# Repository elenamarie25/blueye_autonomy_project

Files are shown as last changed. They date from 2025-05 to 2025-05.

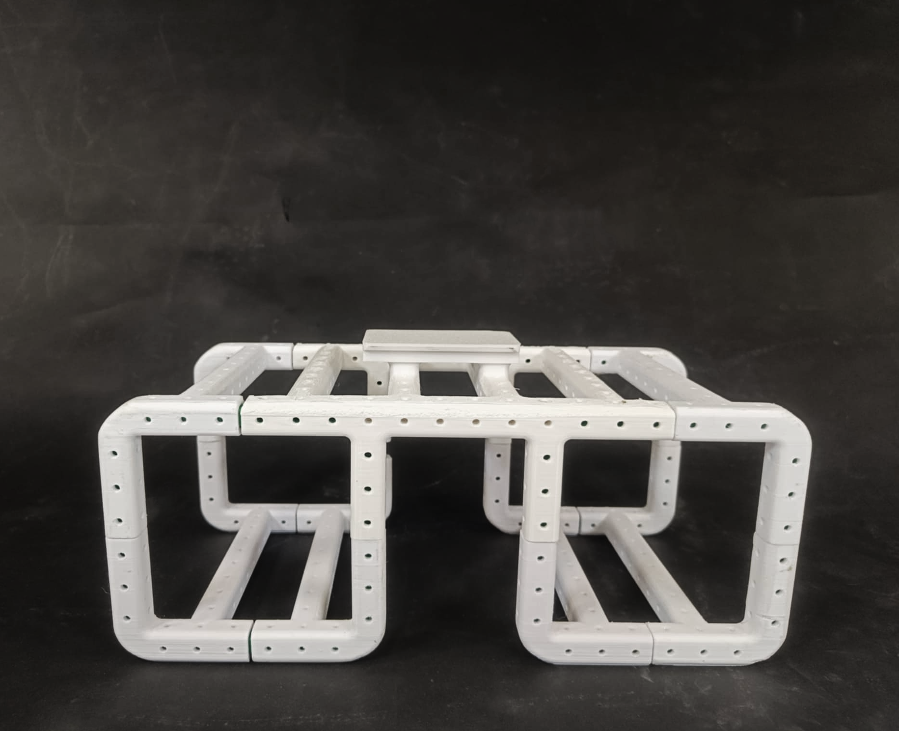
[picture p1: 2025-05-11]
images/Whole frame.png

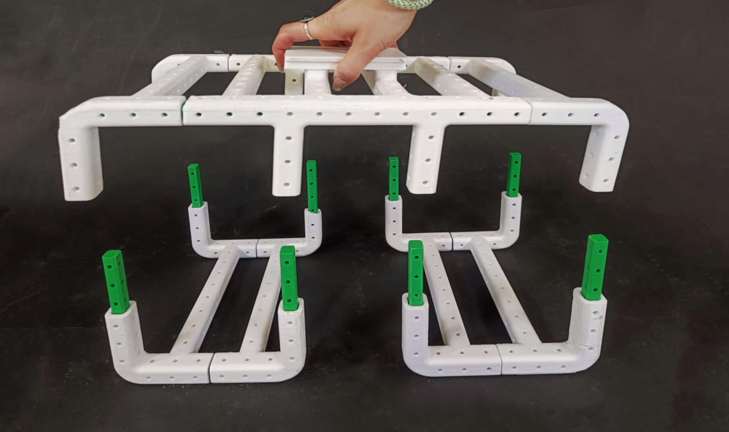
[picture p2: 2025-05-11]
images/Connecting frame.png

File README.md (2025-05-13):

# Modular Sensor Mounting System for Blueye ROV

This open-source library contains 3D-printable mounting solutions for attaching various sensors to the Blueye ROV.

The mounts are designed to fit specific sensors such as:
- USBL modem
- DVL (Doppler Velocity Log)
- Compute Bottle
- Forward-looking sonar
- Inductive charging coil

## 🔧 Customization
The files are provided in .STL (ready to print) and .STEP (editable) formats as well as CAD links so that users can adapt the mounts for their own sensor configurations or ROV modifications.

## 📦 What's included
- Mounting base designs
- Modular connector elements
- Sensor-specific brackets
- Assembly documentation and How-to's

## 🗂 Folder Overview

- `/original_files/` – Official mounting parts made by our team. Please don’t modify these directly.
- `/community_mods/` – Modified or remixed versions contributed by the community.
- `/images/` – Previews and renders of the models.
- `/how-to/` – Guides for printing, designing and assembling.

## 📄 License
These files are shared under the **Creative Commons Attribution-NonCommercial-ShareAlike 4.0 International (CC BY-NC-SA 4.0)** license.  
This means you're free to remix, adapt, and build upon this work non-commercially, as long as you credit the original creators and license your new creations under the same terms.

## 🛠 Contributing or Remixing

Please **do not modify the files in `/original_files/`**.  
If you'd like to make your own version, upload your modified file to the `/community_mods/` folder and include your name or version in the filename.

This keeps the original library intact while allowing remixing and experimentation.

## ✉️ Contact
If you use or modify this project, feel free to share your results or improvements.  
Developed by design students at NTNU as part of the Spring 2024 course "Design 6 – Futures" in collaboration with Blueye Robotics.

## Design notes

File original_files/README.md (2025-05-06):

## 🗂 original_files
Official mounting parts made by our team. Please don’t modify these directly.

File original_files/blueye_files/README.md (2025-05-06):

## 🗂 blueye_files
The origional CAD models for the Blueye sensors and Blueye robot.

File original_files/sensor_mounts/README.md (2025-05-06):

## 🗂 sensor_mounts
The sensor mounts for the sensors used in the Blueye AUV project

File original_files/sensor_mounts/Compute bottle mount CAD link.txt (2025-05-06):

Compute bottle mount link:
https://a360.co/4m7CdN2

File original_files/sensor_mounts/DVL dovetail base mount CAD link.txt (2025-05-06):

DVL dovetail base mount link
https://a360.co/42Lx19Z

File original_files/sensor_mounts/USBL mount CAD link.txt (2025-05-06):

USBL mount link:
https://a360.co/3Sn9JRv

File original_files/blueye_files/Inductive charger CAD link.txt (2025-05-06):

Inductive charger link:
https://a360.co/3SkSkZM

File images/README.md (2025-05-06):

## 🗂 images
Previews and renders of the models.

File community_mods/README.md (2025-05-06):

## 🗂 community_mods
Modified or remixed versions contributed by the community.

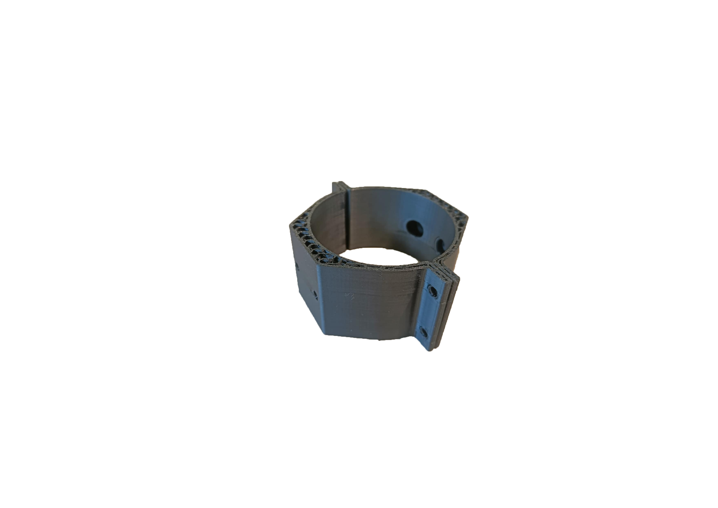
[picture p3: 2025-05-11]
images/USBL mount.png

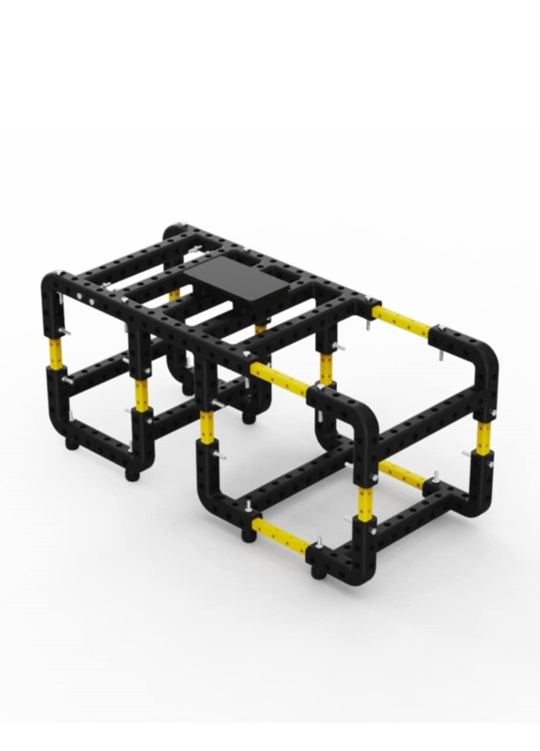
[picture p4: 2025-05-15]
images/Frame render.jpeg

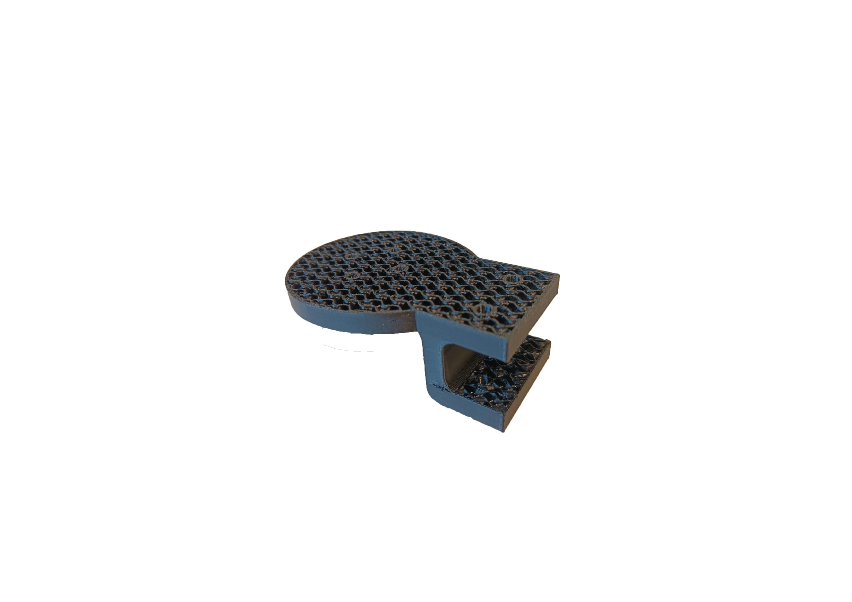
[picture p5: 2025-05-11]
images/DVL mount.png

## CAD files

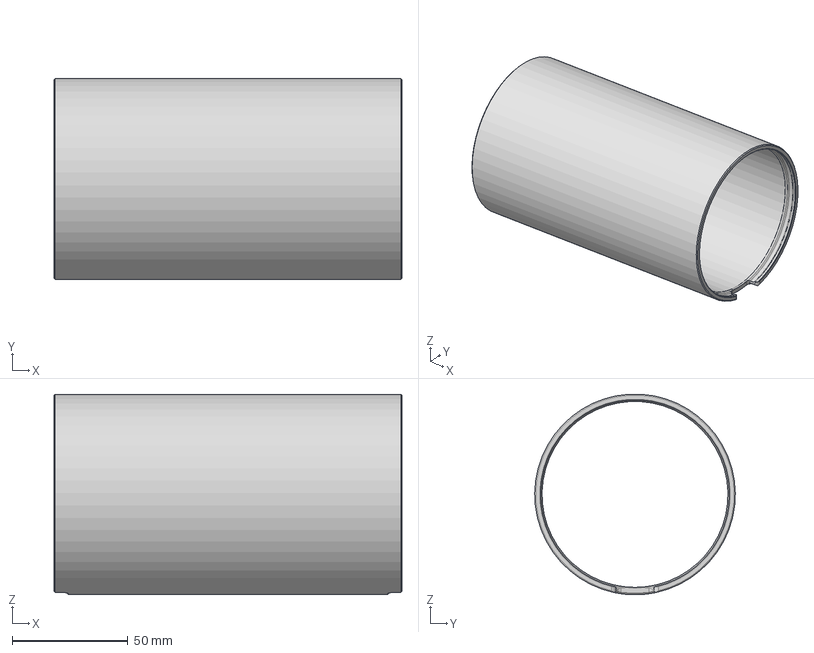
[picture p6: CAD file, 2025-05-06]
original_files/blueye_files/WTE3-M-LOCKING-TUBE-150-R2 v1.step
150.0 x 86.5 x 86.4 mm

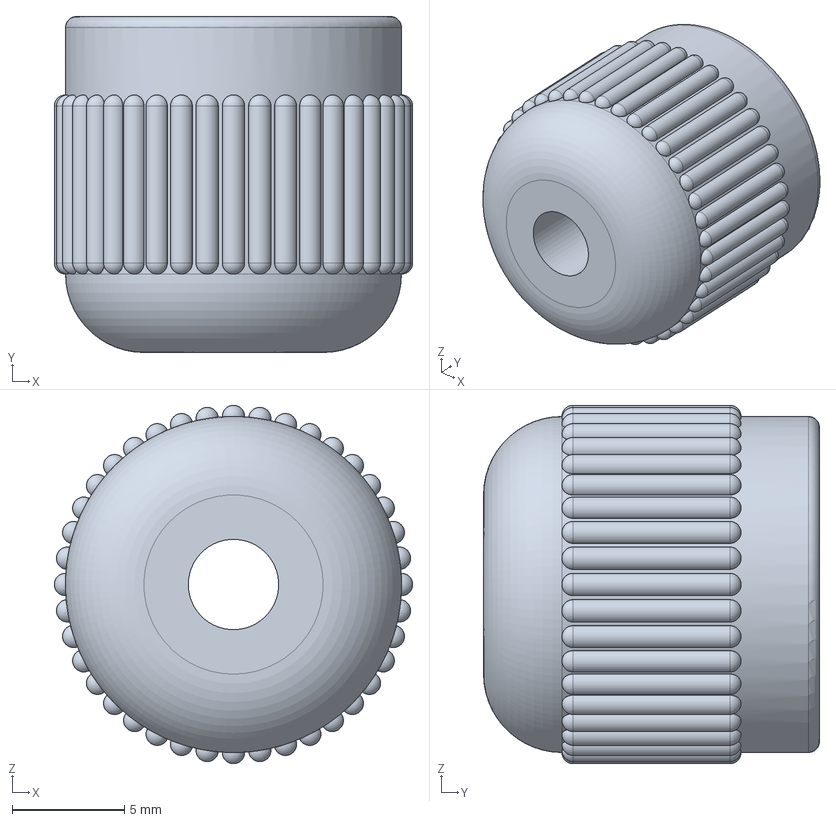
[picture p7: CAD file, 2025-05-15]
original_files/frame/Base supports.step
16.0 x 15.0 x 16.0 mm

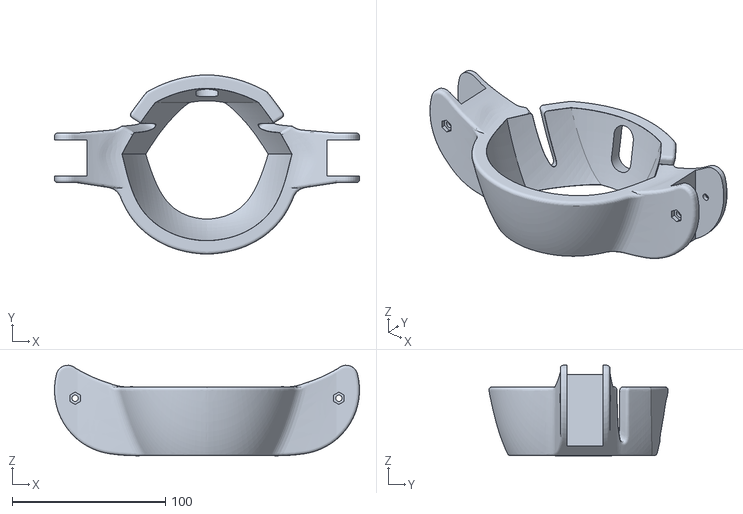
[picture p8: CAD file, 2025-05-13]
original_files/sensor_mounts/Top mount rear.stl
199.1 x 117.0 x 59.1

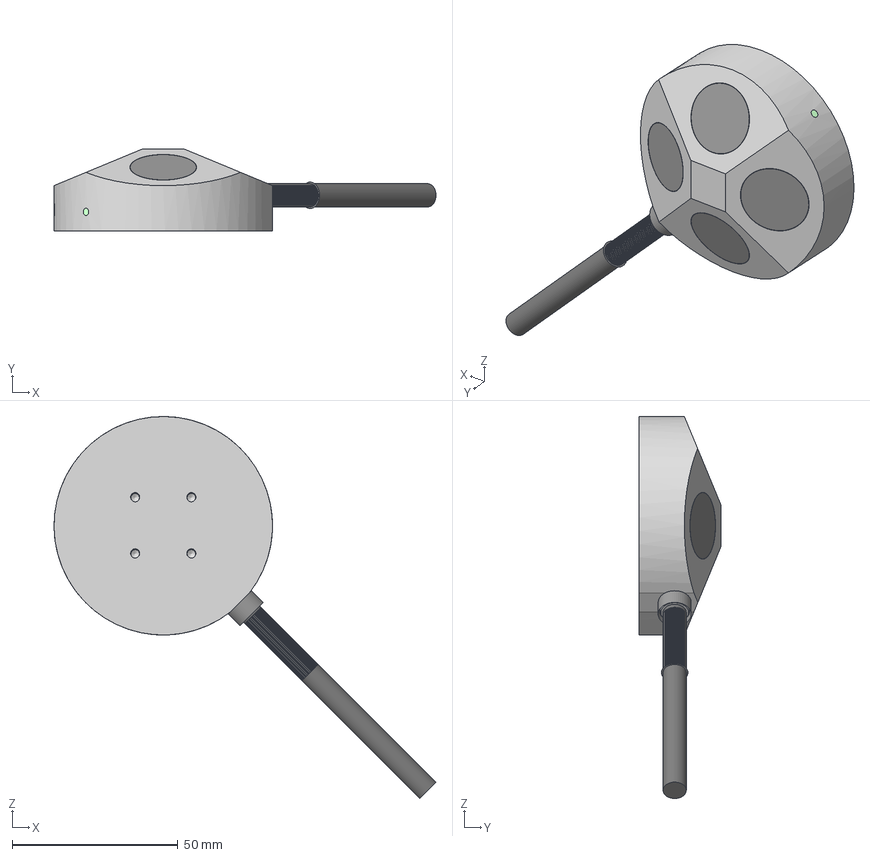
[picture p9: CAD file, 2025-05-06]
original_files/blueye_files/WL-11007-1_DVL.step
115.4 x 24.8 x 115.4 mm

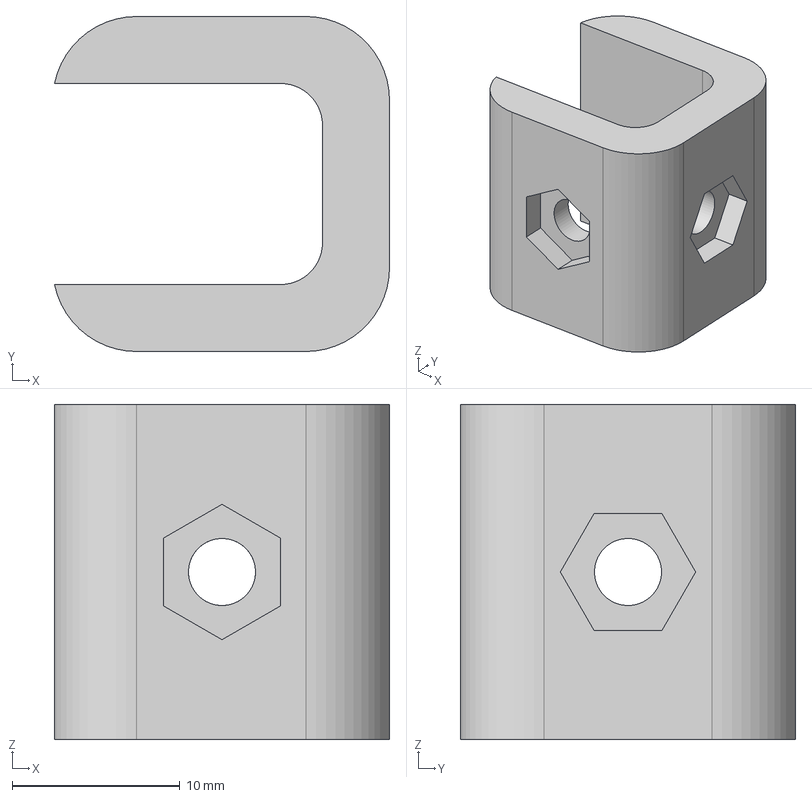
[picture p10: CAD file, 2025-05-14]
original_files/frame/Add on's.step
20.0 x 20.0 x 20.0 mm

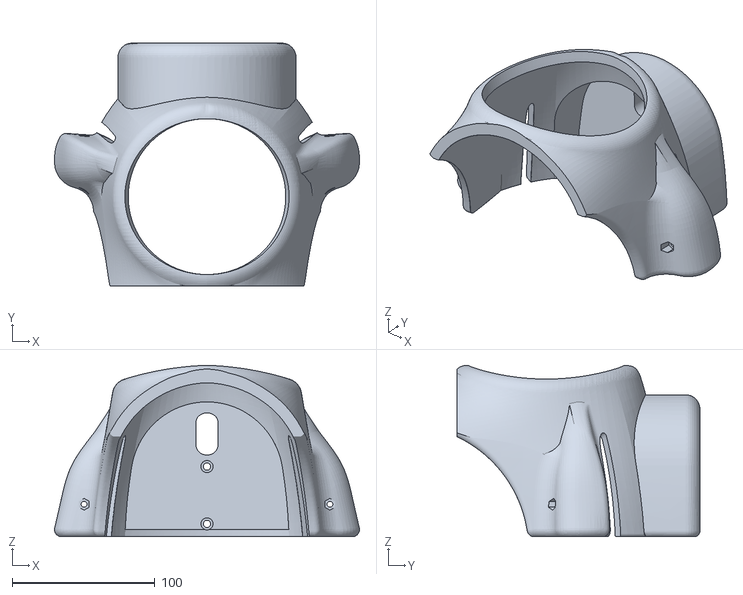
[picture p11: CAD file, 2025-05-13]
original_files/sensor_mounts/Top mount front.stl
213.5 x 170.0 x 120.0

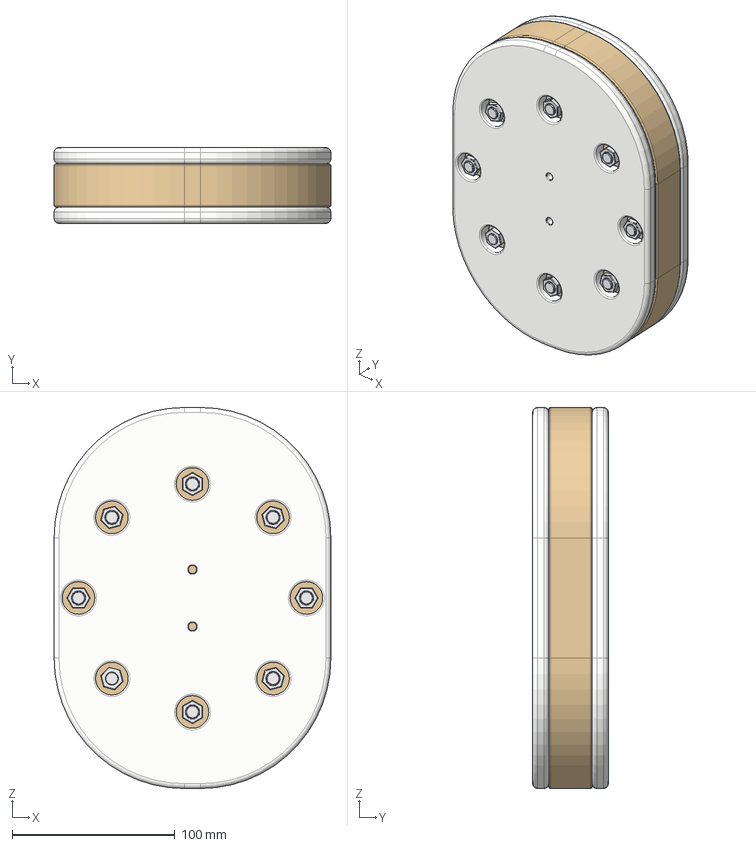
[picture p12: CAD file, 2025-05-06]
original_files/blueye_files/Inductive charger.step
170.0 x 46.5 x 234.0 mm

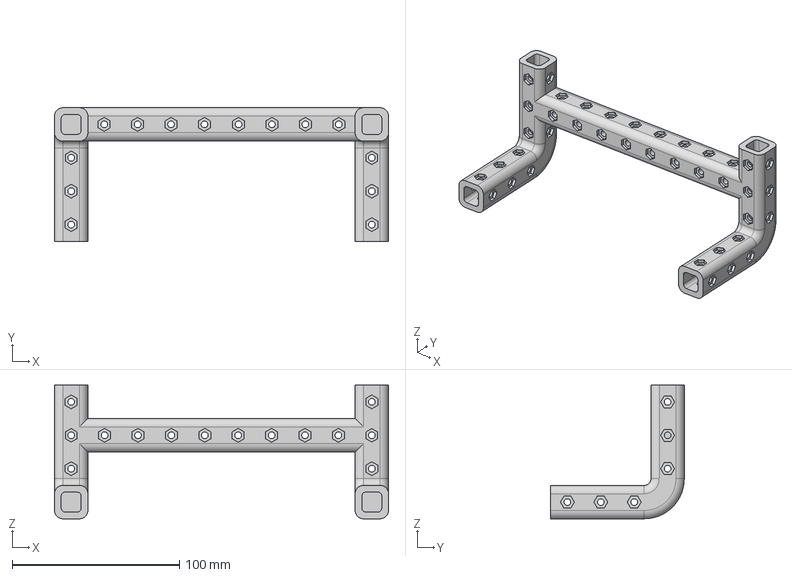
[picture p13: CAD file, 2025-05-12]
original_files/frame/Corner piece.step
200.0 x 80.0 x 80.0 mm

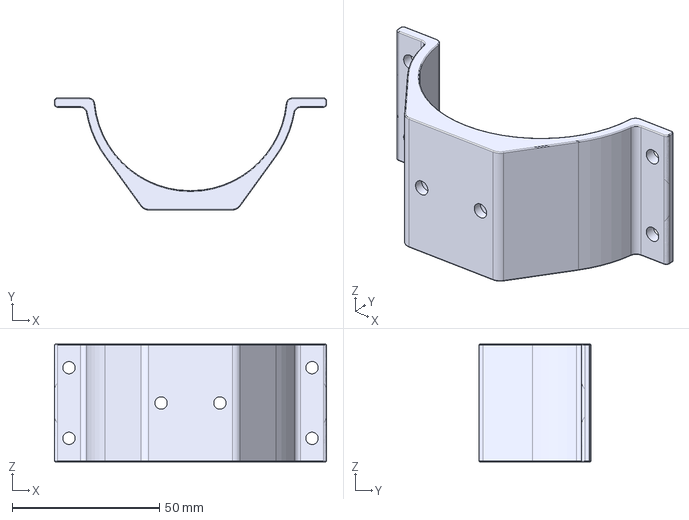
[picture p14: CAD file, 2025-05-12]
original_files/sensor_mounts/USBL mount.step
92.4 x 38.1 x 40.0 mm

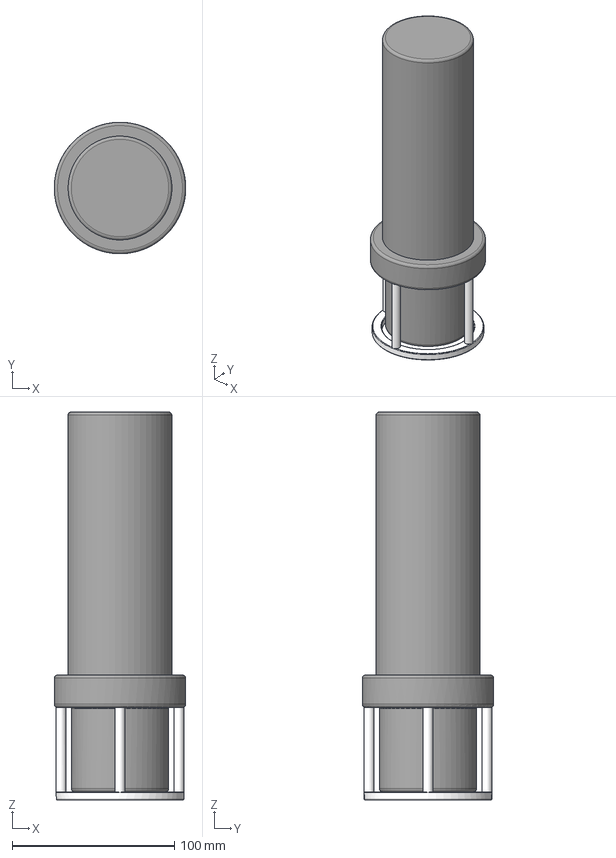
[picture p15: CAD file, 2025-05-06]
original_files/blueye_files/USBL.step
81.0 x 81.0 x 239.0 mm

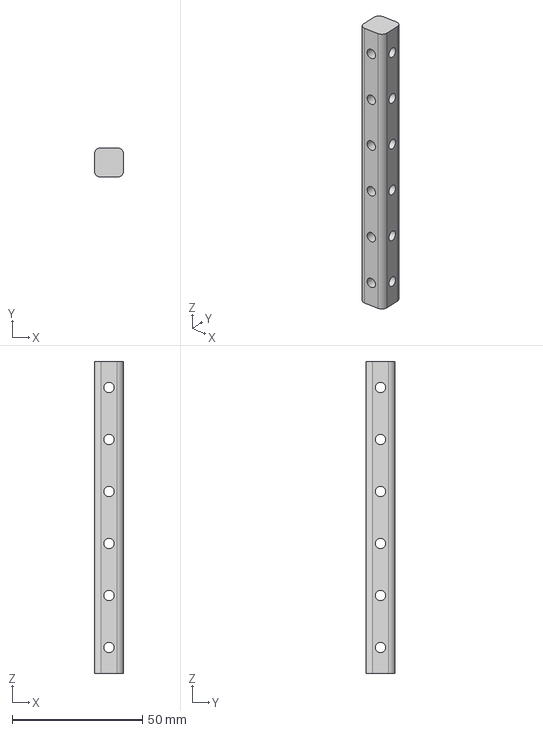
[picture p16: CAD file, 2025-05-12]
original_files/frame/Connecting piece.step
11.3 x 11.3 x 120.0 mm

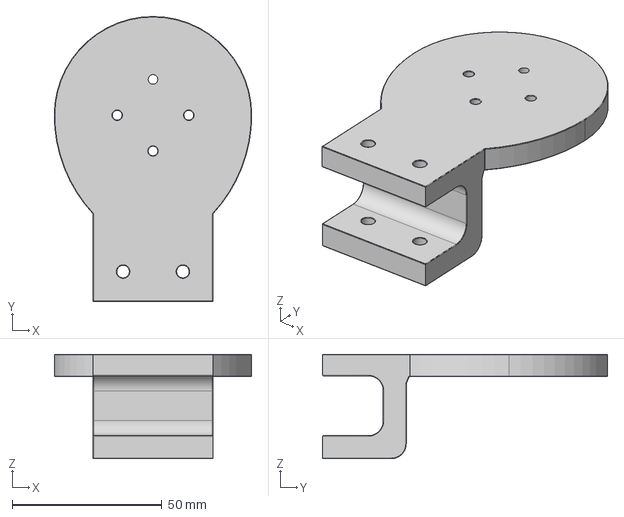
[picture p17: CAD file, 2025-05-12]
original_files/sensor_mounts/Dvl mount.step
66.0 x 95.3 x 34.9 mm

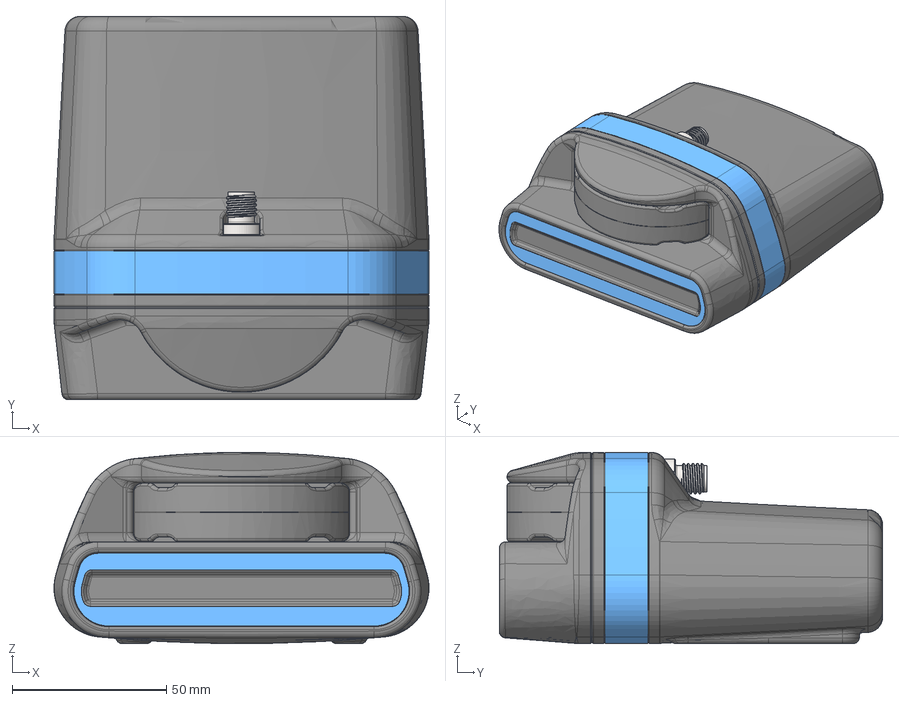
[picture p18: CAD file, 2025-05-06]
original_files/blueye_files/Oculus M-Series Sonar.step
121.6 x 124.3 x 62.0 mm

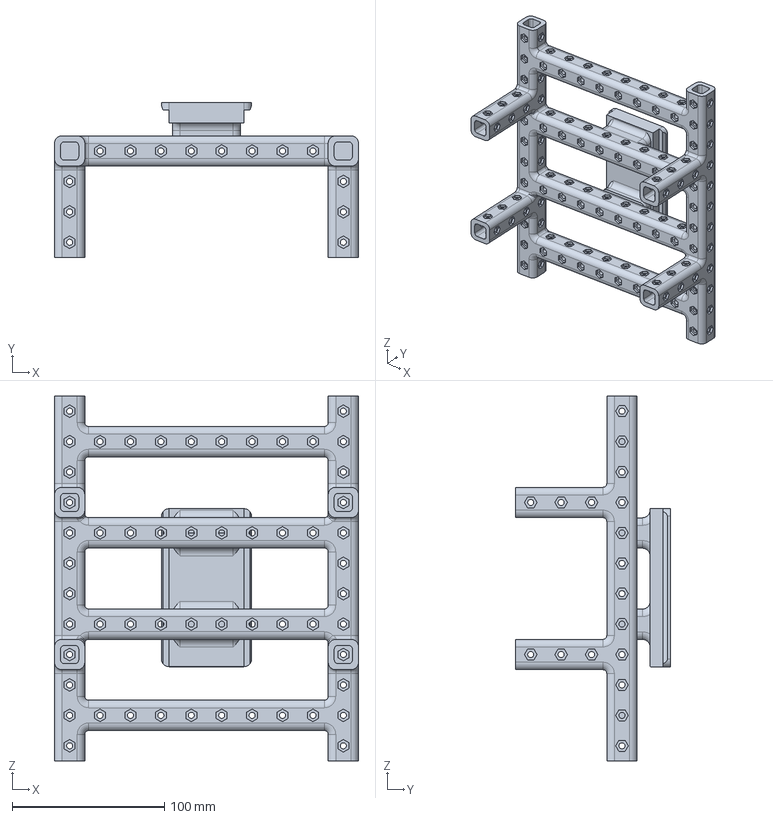
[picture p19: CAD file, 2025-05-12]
original_files/frame/Middle piece.step
200.0 x 101.9 x 240.0 mm

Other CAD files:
original_files/sensor_mounts/sonar mount.step
original_files/blueye_files/Oculus M-Series Sonar v1.stl
original_files/sensor_mounts/Compute bottle mount.step
original_files/sensor_mounts/DVL P001 dovetail base mount.step
original_files/blueye_files/Inductive charger.stl
original_files/blueye_files/USBL.stl
original_files/blueye_files/WL-11007-1_DVL.stl
original_files/blueye_files/WTE3-M-LOCKING-TUBE-150-R2 v1.stl
original_files/frame/Add on's.stl
original_files/frame/Base supports.stl
original_files/frame/Connecting piece.stl
original_files/frame/Corner piece.stl
original_files/frame/Middle piece.stl
original_files/sensor_mounts/Compute bottle mount.stl
original_files/sensor_mounts/DVL P001 dovetail base mount.stl
original_files/sensor_mounts/Dvl mount.stl
original_files/sensor_mounts/USBL mount.stl
original_files/sensor_mounts/sonar mount.stl

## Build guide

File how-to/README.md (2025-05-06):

## 🗂 how-to
Guides for setting up and printing the frame as well as designing and printing the sensor fasteners

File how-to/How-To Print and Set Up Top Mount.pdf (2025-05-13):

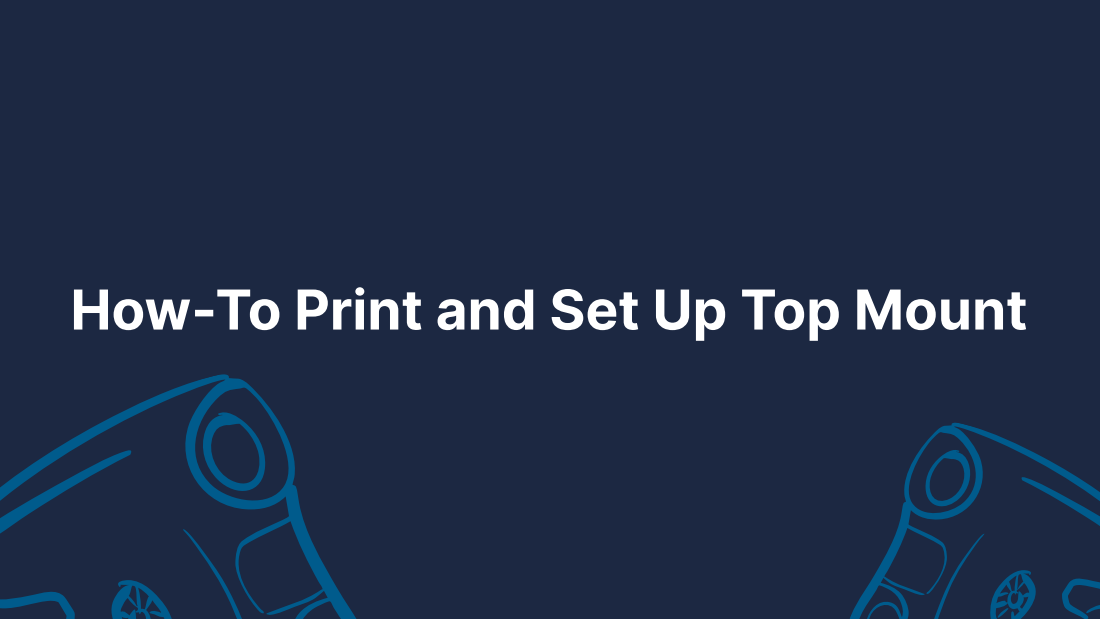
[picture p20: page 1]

How-To Print and Set Up Top Mount

To make the parts airtight increase
to | . It is also
recommended to set
to for increased
durability.

infill density 100%
wall loops/

thickness 5

Airtight and
100% infill

# How-To Print Top Mount

## Printer settings to be mindful of

x Import file into your preferred slicer program.

{x Settings to be mindful ofu
s Filament. Recommended to use
. These work well in saltwaterx
n 100% infill vs. open model and gyroid infill

To prevent implosion in deeper waters, the parts
should either be | or | to let water
run through. Which setting you should use when depends on the desired durability, and which one we recommend for which part is specified in the guides on the next slides.

PETG or PETG-CF

100% infill open

Note:
The examples are from the bamboo slicer but equivalent settings will exist on every slicer program. You only need to change the specified settings, the

rest is fine as-is.

To make an open solution, set
and/or | to | and
change | pattern to

## top bottom shell layer 0 sparse infill “Gyroid”

## Open model and

gyroid infill

# How-To Print Top Mount

## Top Mount - Front piece

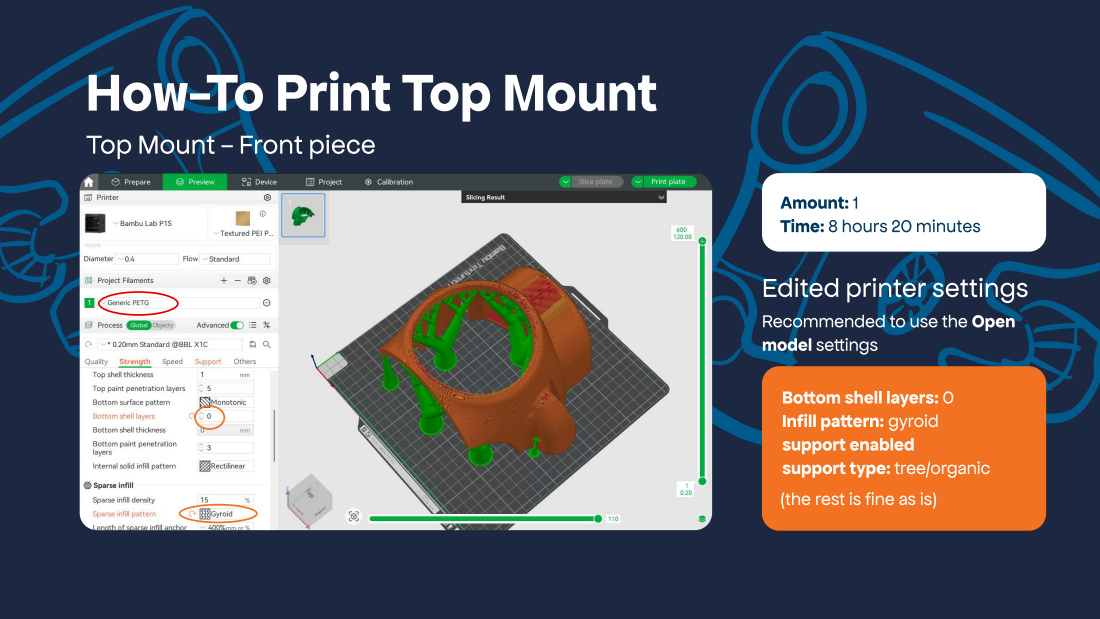
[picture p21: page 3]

Amount: 1
Time: 8 hours 20 minutes

Edited printer settings

Recommended to use the Open
model settings

Bottom shell layers: 0
Infill pattern: gyroid
support enabled
support type: tree/organic

(the rest is fine as is)

# How-To Print Top Mount

# Top Mount - Rear piece

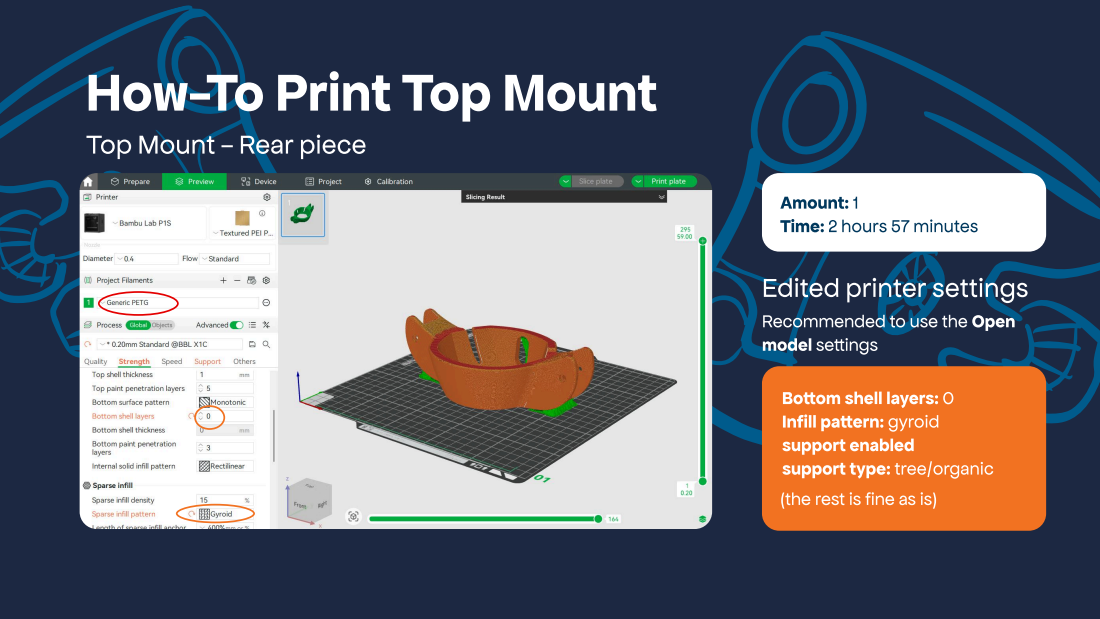
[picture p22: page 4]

Amount: 1
Time: 2 hours 57 minutes

Edited printer settings

Recommended to use the Open
model settings

Bottom shell layers: 0
Infill pattern: gyroid
support enabled
support type: tree/organic
(the rest is fine as is)

# How-To Set Up Top Mount

# Prepare

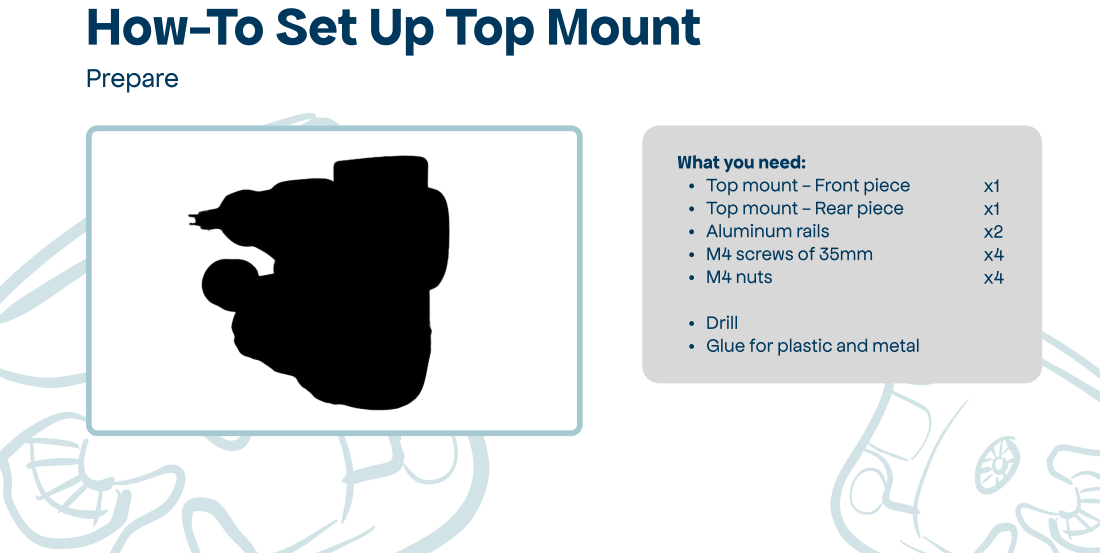
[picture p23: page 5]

What you need:)
' Top mount - Front piece )
' Top mount - Rear piece)
' Aluminum rails)
' M4 screws of 35mm )
' M4 nuts)

' Dril
' Glue for plastic and metal

# How-To Set Up Top Mount

# Prepare aluminium rails

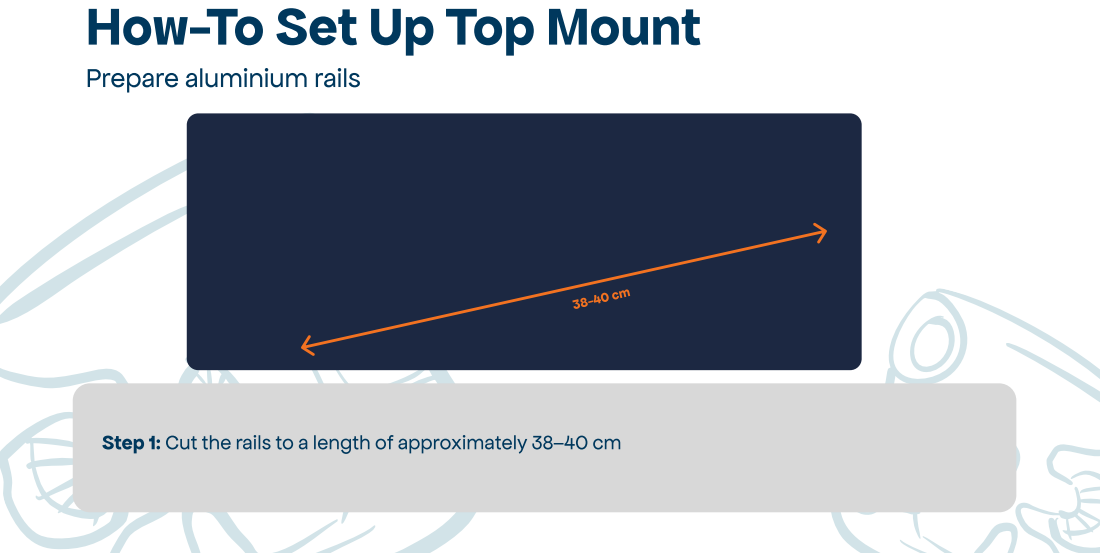
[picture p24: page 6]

Step 1: Cut the rails to a length of approximately 38–40 cm

# How-To Set Up Top Mount

# Prepare aluminium rails

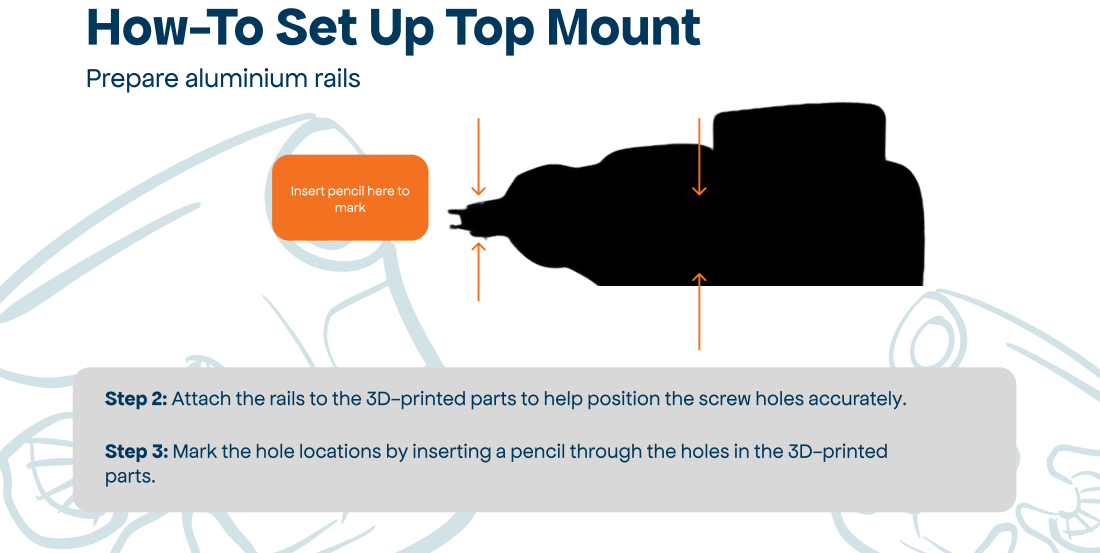
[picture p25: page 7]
mark

Insert pencil here to

Step 2: Attach the rails to the 3D-printed parts to help position the screw holes accurately.

Step 3: Mark the hole locations by inserting a pencil through the holes in the 3D-printed
parts.

# How-To Set Up Top Mount

# Prepare aluminium rails

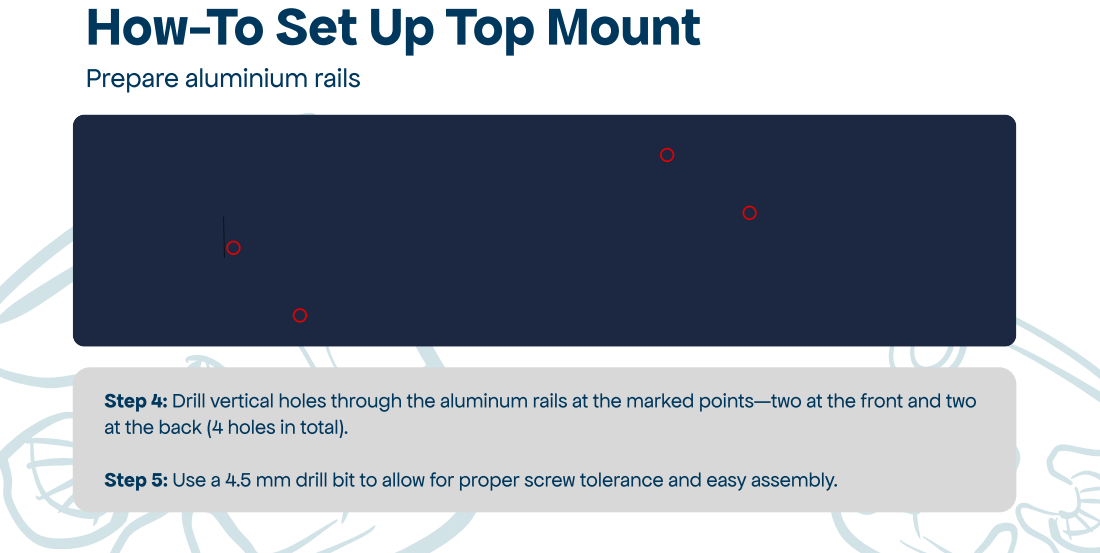
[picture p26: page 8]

Step 4: Drill vertical holes through the aluminum rails at the marked points—two at the front and two
at the back (4 holes in total).

Step 5: Use a 4.5 mm drill bit to allow for proper screw tolerance and easy assembly.

# How-To Set Up Top Mount

Prepare front and rear pieces.

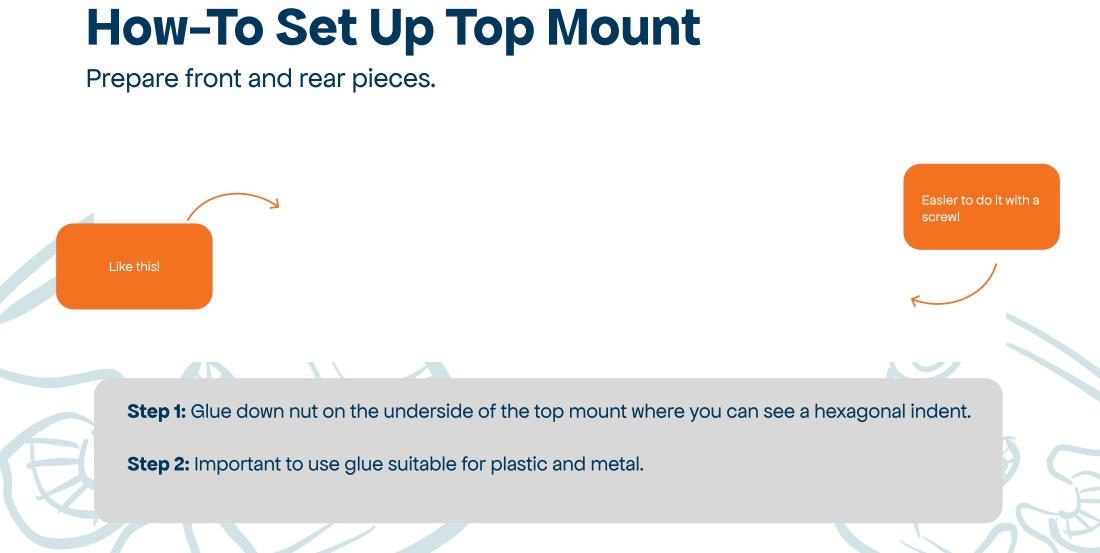
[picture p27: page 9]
Like this!

Easier to do it with a
screw!

Step 1: Glue down nut on the underside of the top mount where you can see a hexagonal indent.

Step 2: Important to use glue suitable for plastic and metal.

# How-To Set Up Top Mount

## Assembly (with inductive charger)

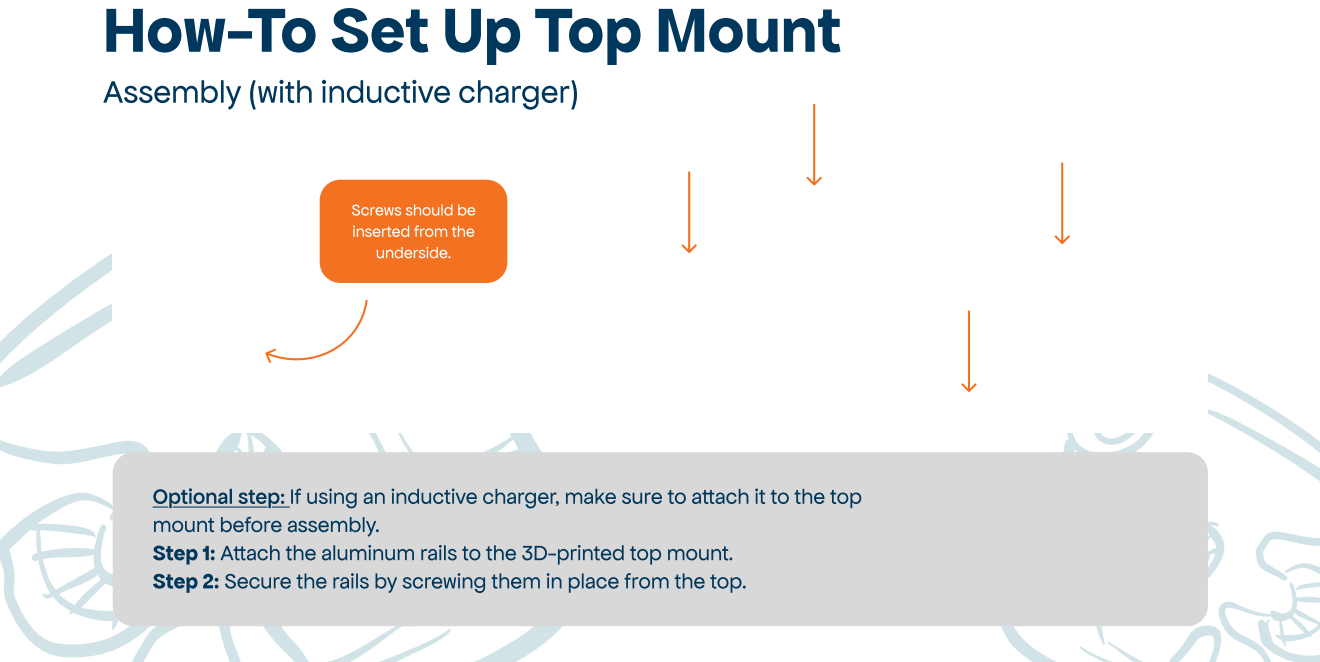
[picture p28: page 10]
underside.

Screws should be

inserted from the

Optional step: If using an inductive charger, make sure to attach it to the top

mount before assembly.
Step 1: Attach the aluminum rails to the 3D-printed top mount.

Step 2: Secure the rails by screwing them in place from the top.

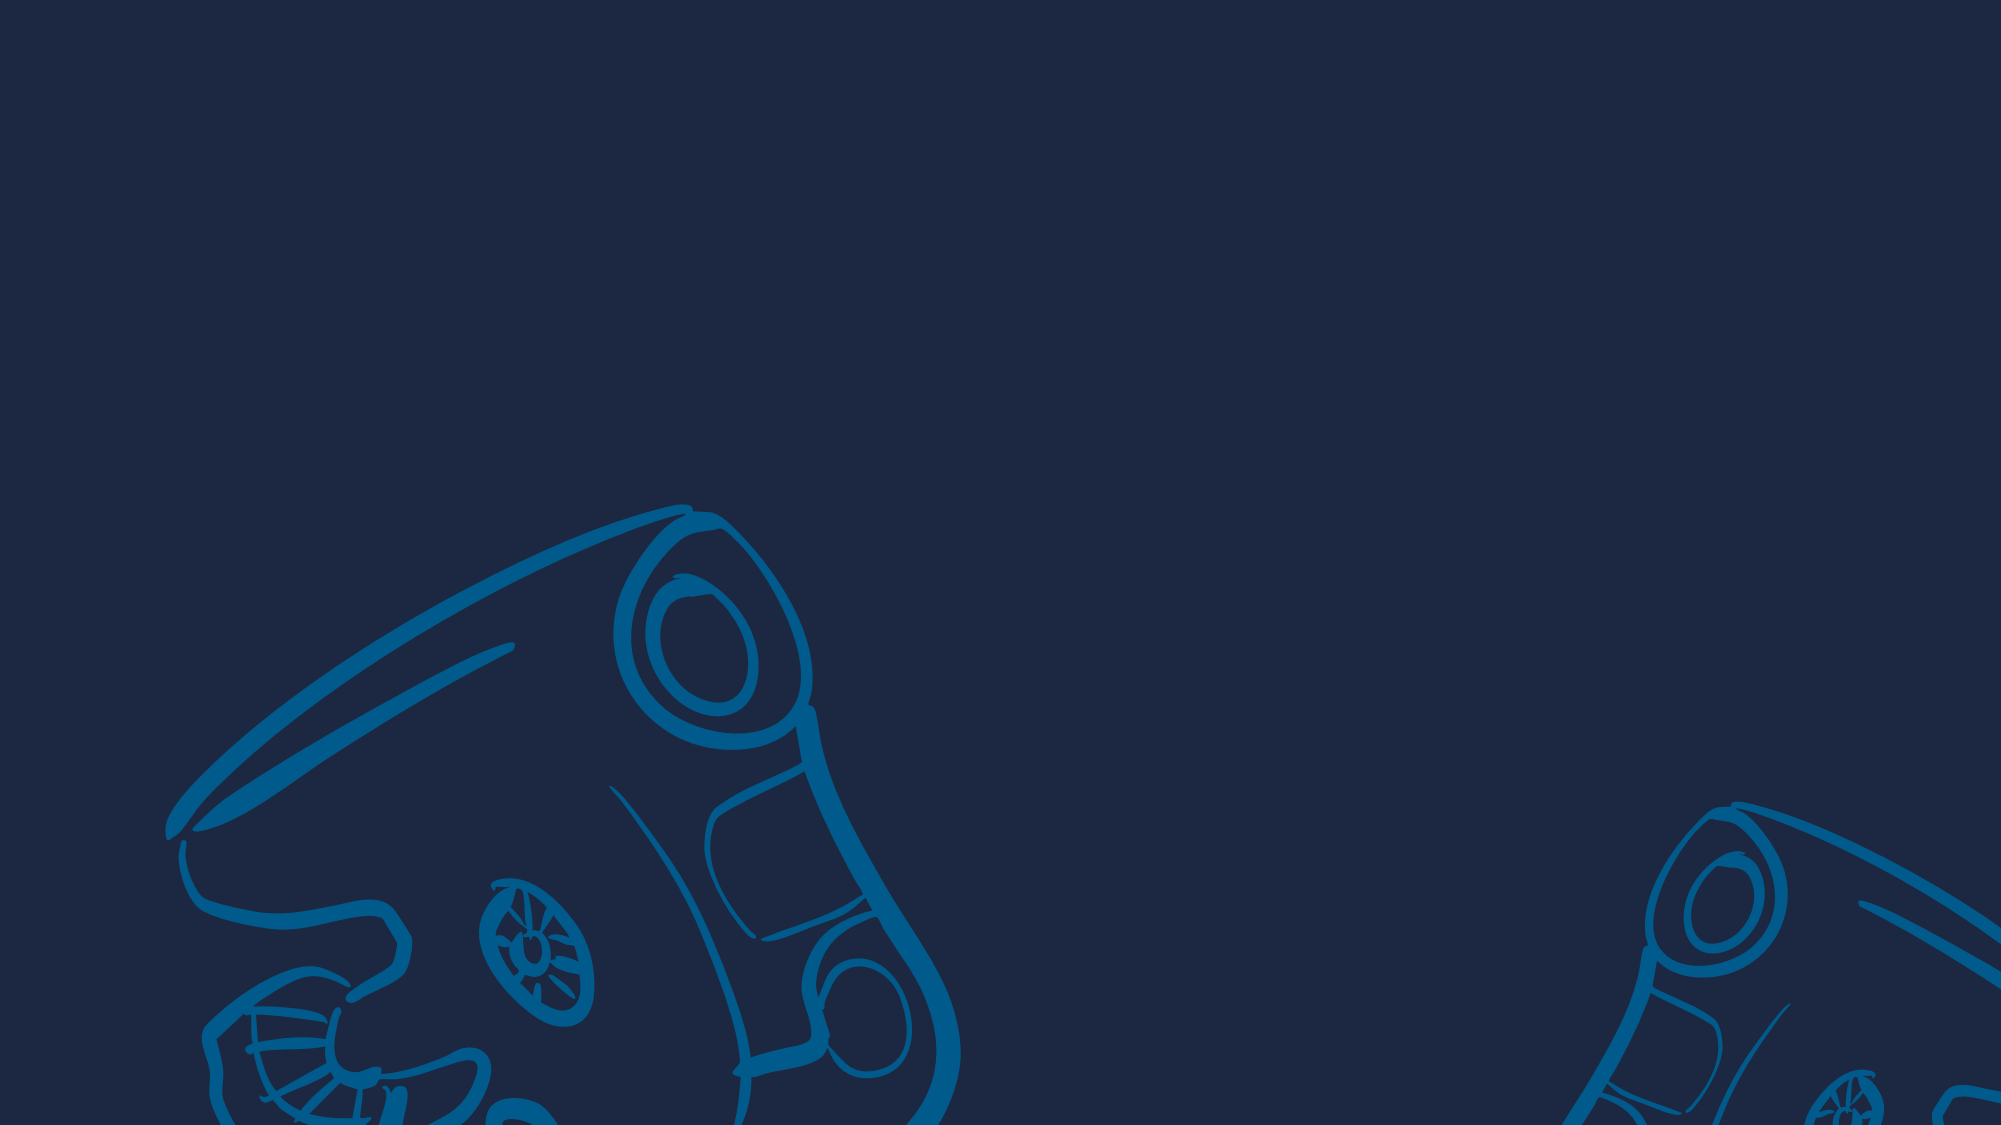
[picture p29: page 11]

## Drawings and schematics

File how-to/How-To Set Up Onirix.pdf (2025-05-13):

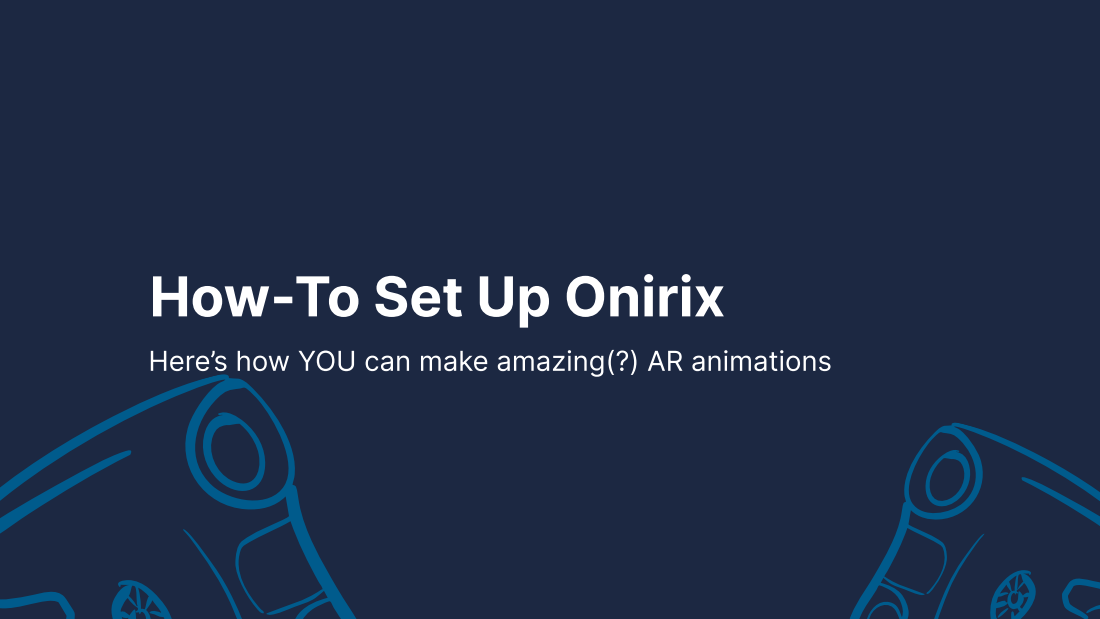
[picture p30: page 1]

How-To Set Up Onirix

Here’s how YOU can make amazing(?) AR animations

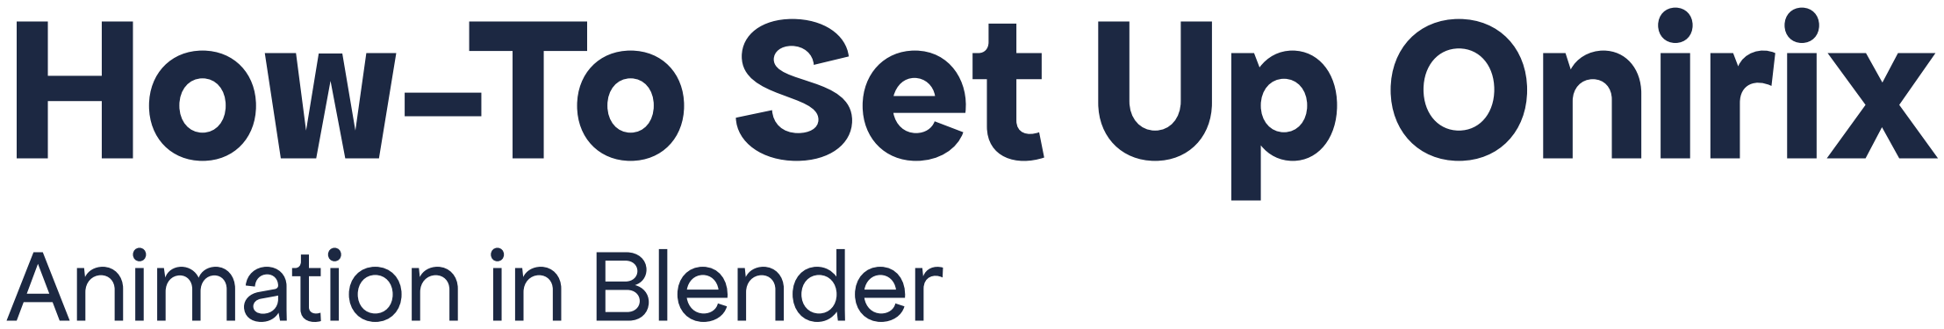
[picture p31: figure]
How-To Set Up Onirix; Animation in Blender
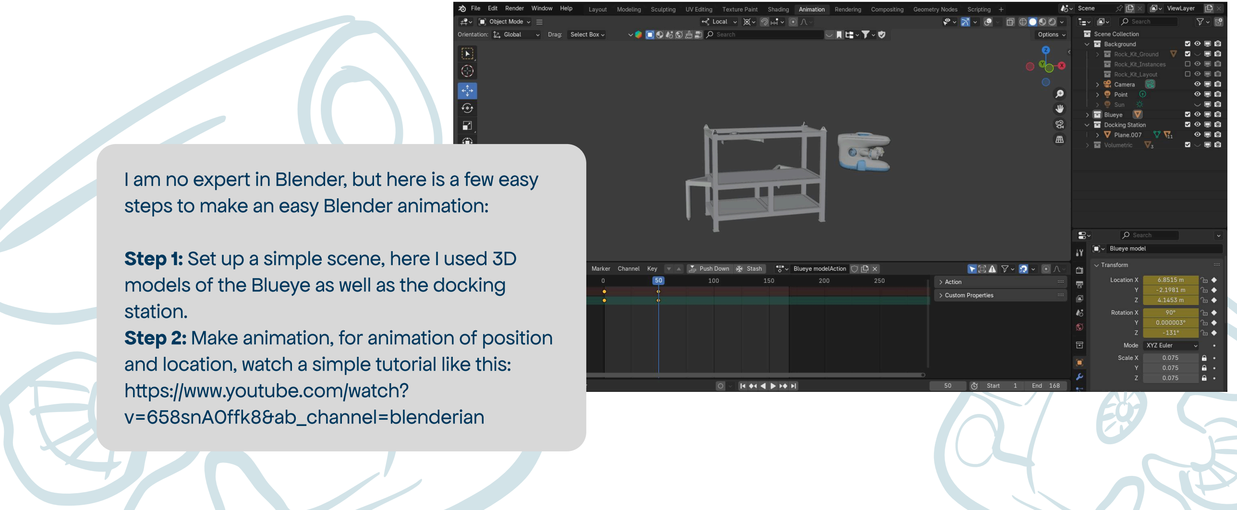
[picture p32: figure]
station.; https://www.youtube.com/watch?; v=658snA0ffk8&ab_channel=blenderian

I am no expert in Blender, but here is a few easy steps to make an easy Blender animation:

Step 1: Set up a simple scene, here I used 3D models of the Blueye as well as the docking
Step 2: Make animation, for animation of position and location, watch a simple tutorial like this:

# How-To Set Up Onirix

## Export animation

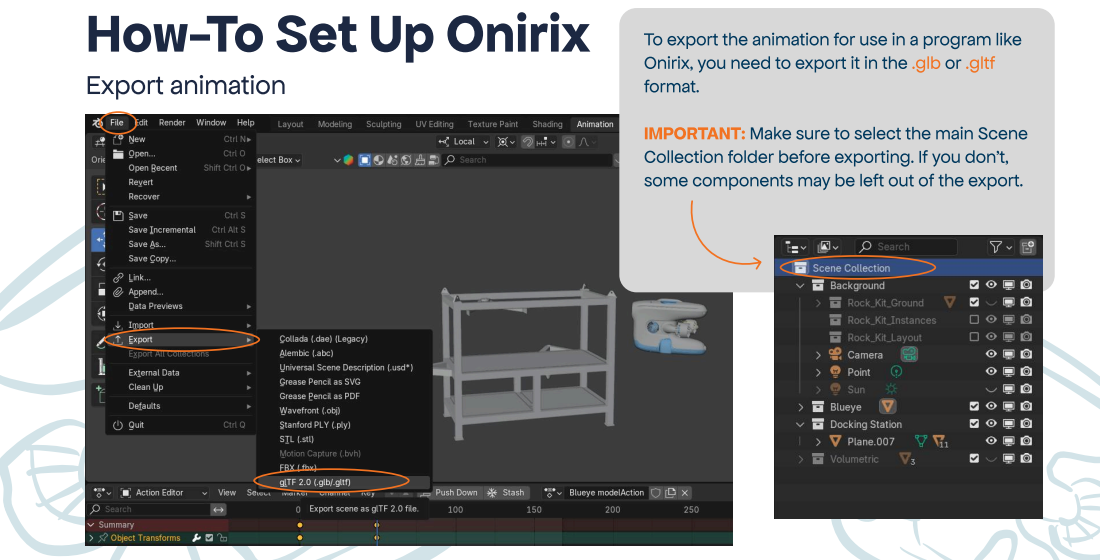
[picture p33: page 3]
Onirix, you need to export it in the; .glb; .gltf

To export the animation for use in a program like
format.

IMPORTANT:
Collection folder before exporting. If you don't,
some components may be left out of the export.

Make sure to select the main Scene

# How-To Set Up Onirix

# Set up project in Onirix

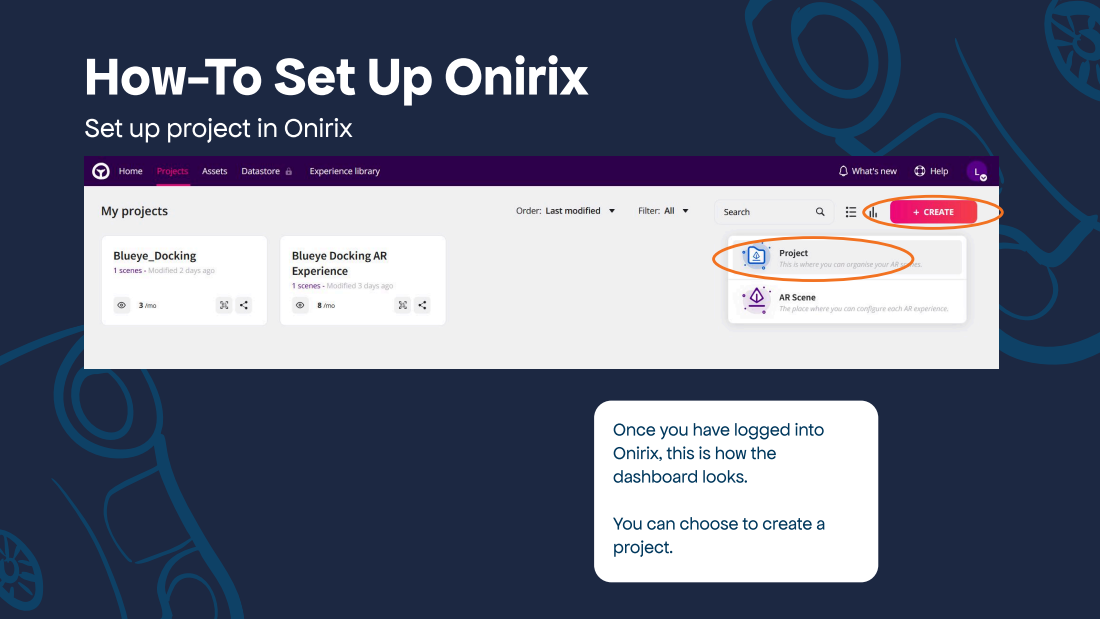
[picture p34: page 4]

Once you have logged into
Onirix, this is how the
dashboard looks.

You can choose to create a
project.

# How-To Set Up Onirix

## Set up project in Onirix

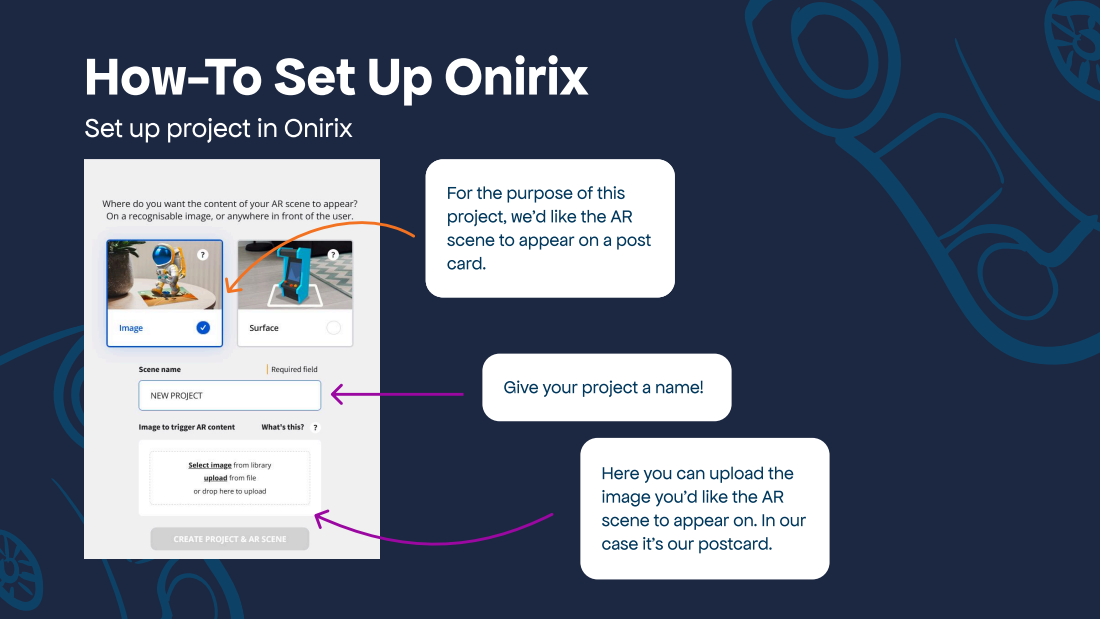
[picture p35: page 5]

For the purpose of this
project, we’d like the AR
scene to appear on a post
card.

Give your project a name!

Here you can upload the
image you’d like the AR
scene to appear on. In our
case it’s our postcard.

# How-To Set Up Onirix

## Import animation

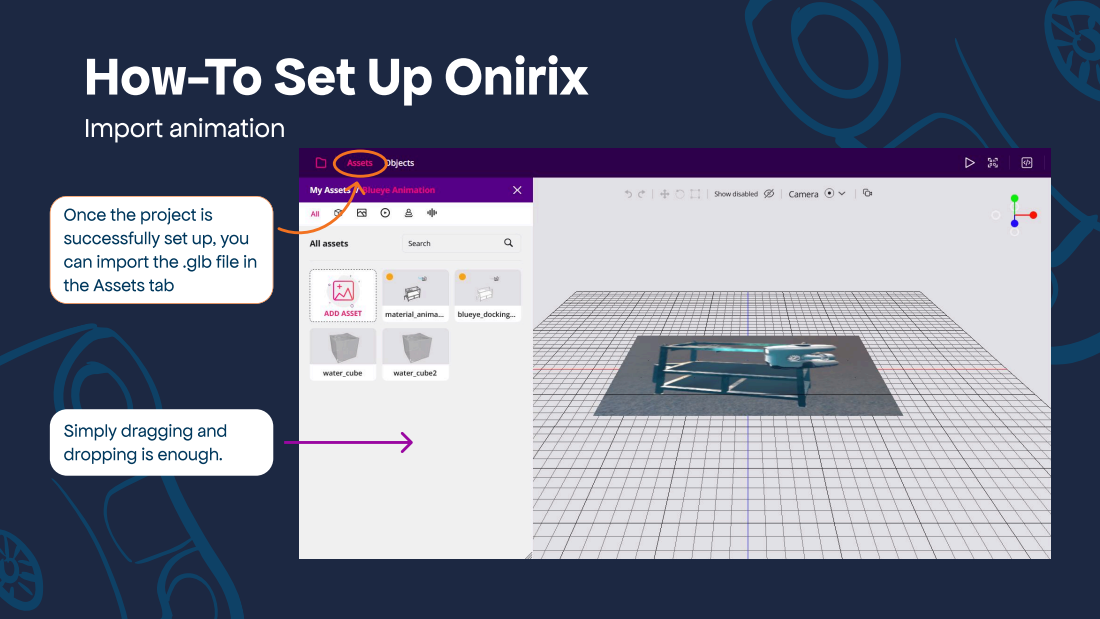
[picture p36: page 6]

Once the project is
successfully set up, you
can import the .glb file in
the Assets tab

Simply dragging and
dropping is enough.

# How-To Set Up Onirix

# Adjust 3D scene

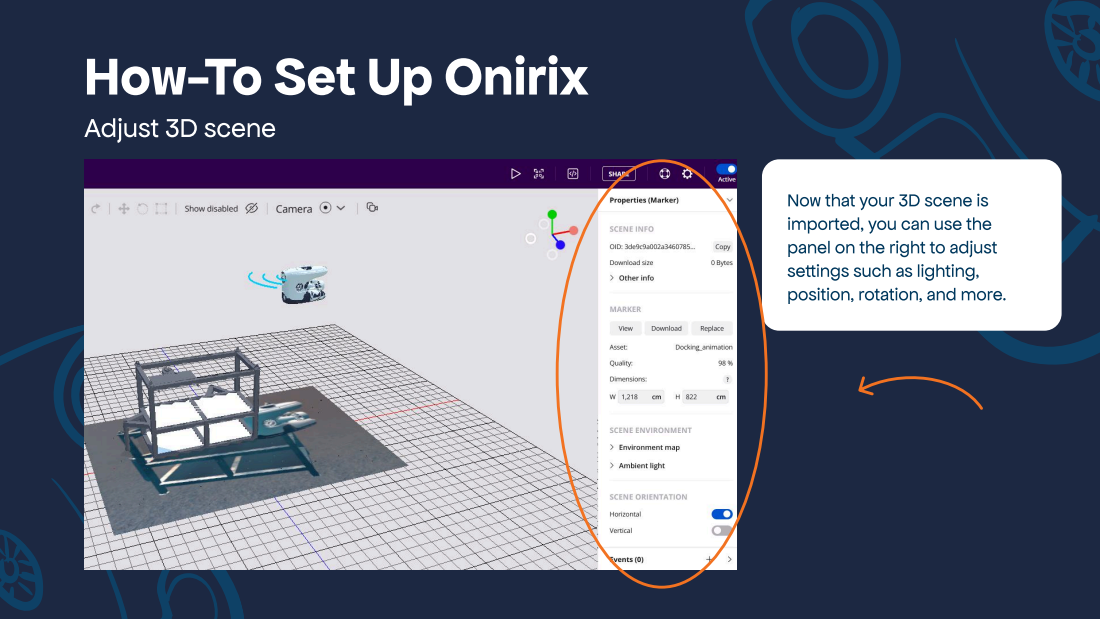
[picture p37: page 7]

Now that your 3D scene is
imported, you can use the
panel on the right to adjust
settings such as lighting,
position, rotation, and more.

# How-To Set Up Onirix

# Insert button

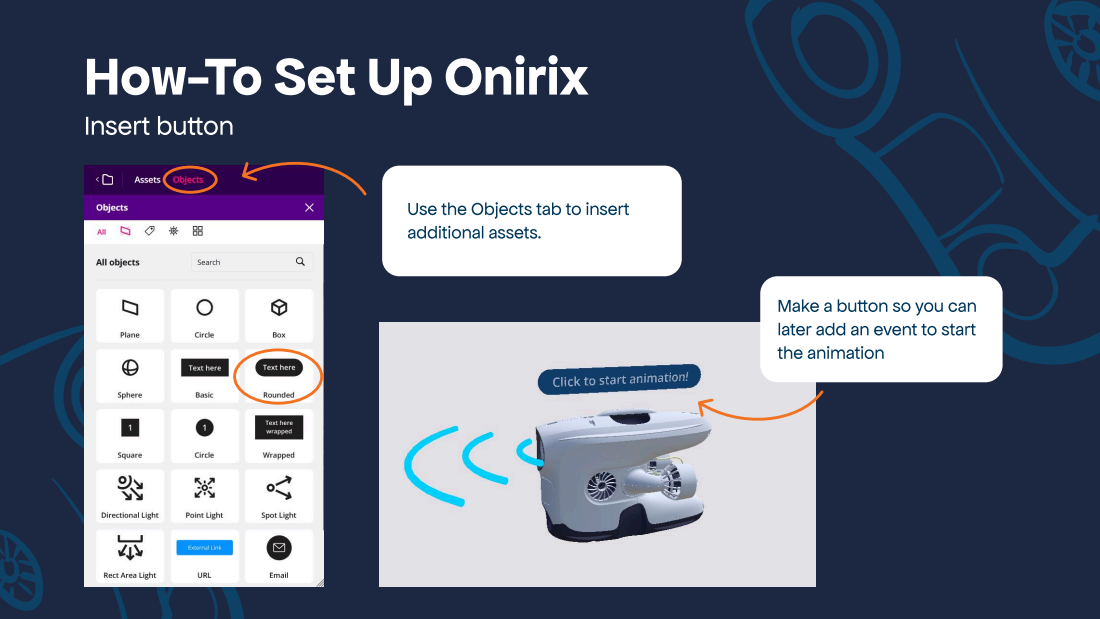
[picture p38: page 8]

Use the Objects tab to insert
additional assets.

Make a button so you can
later add an event to start
the animation

# How-To Set Up Onirix

# Add event

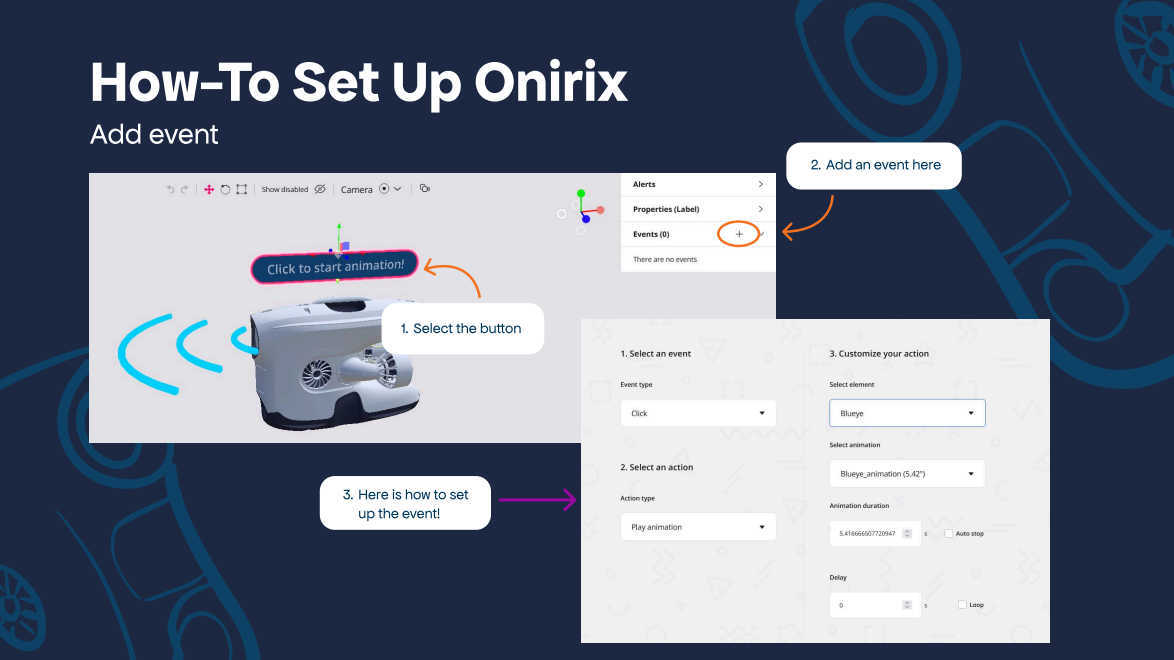
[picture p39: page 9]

=# Add an event here

$# Select the button

2# Here is how to set
up the event!

# How-To Set Up Onirix

# Share AR scene

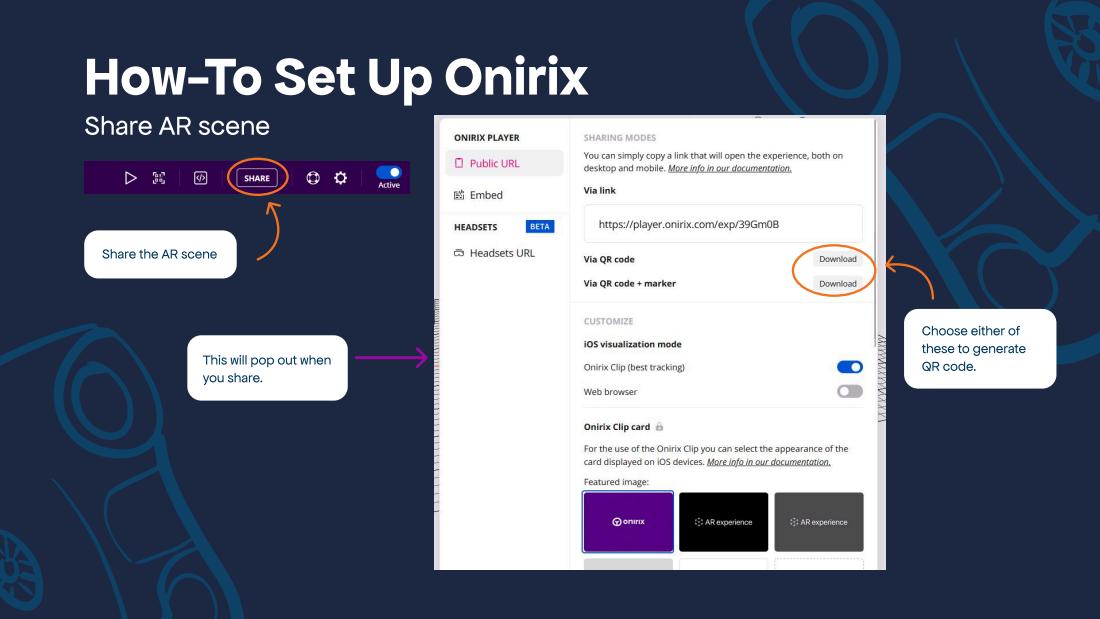
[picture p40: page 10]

Share the AR scene

Choose either of
these to generate
QR code.

This will pop out when
you share.

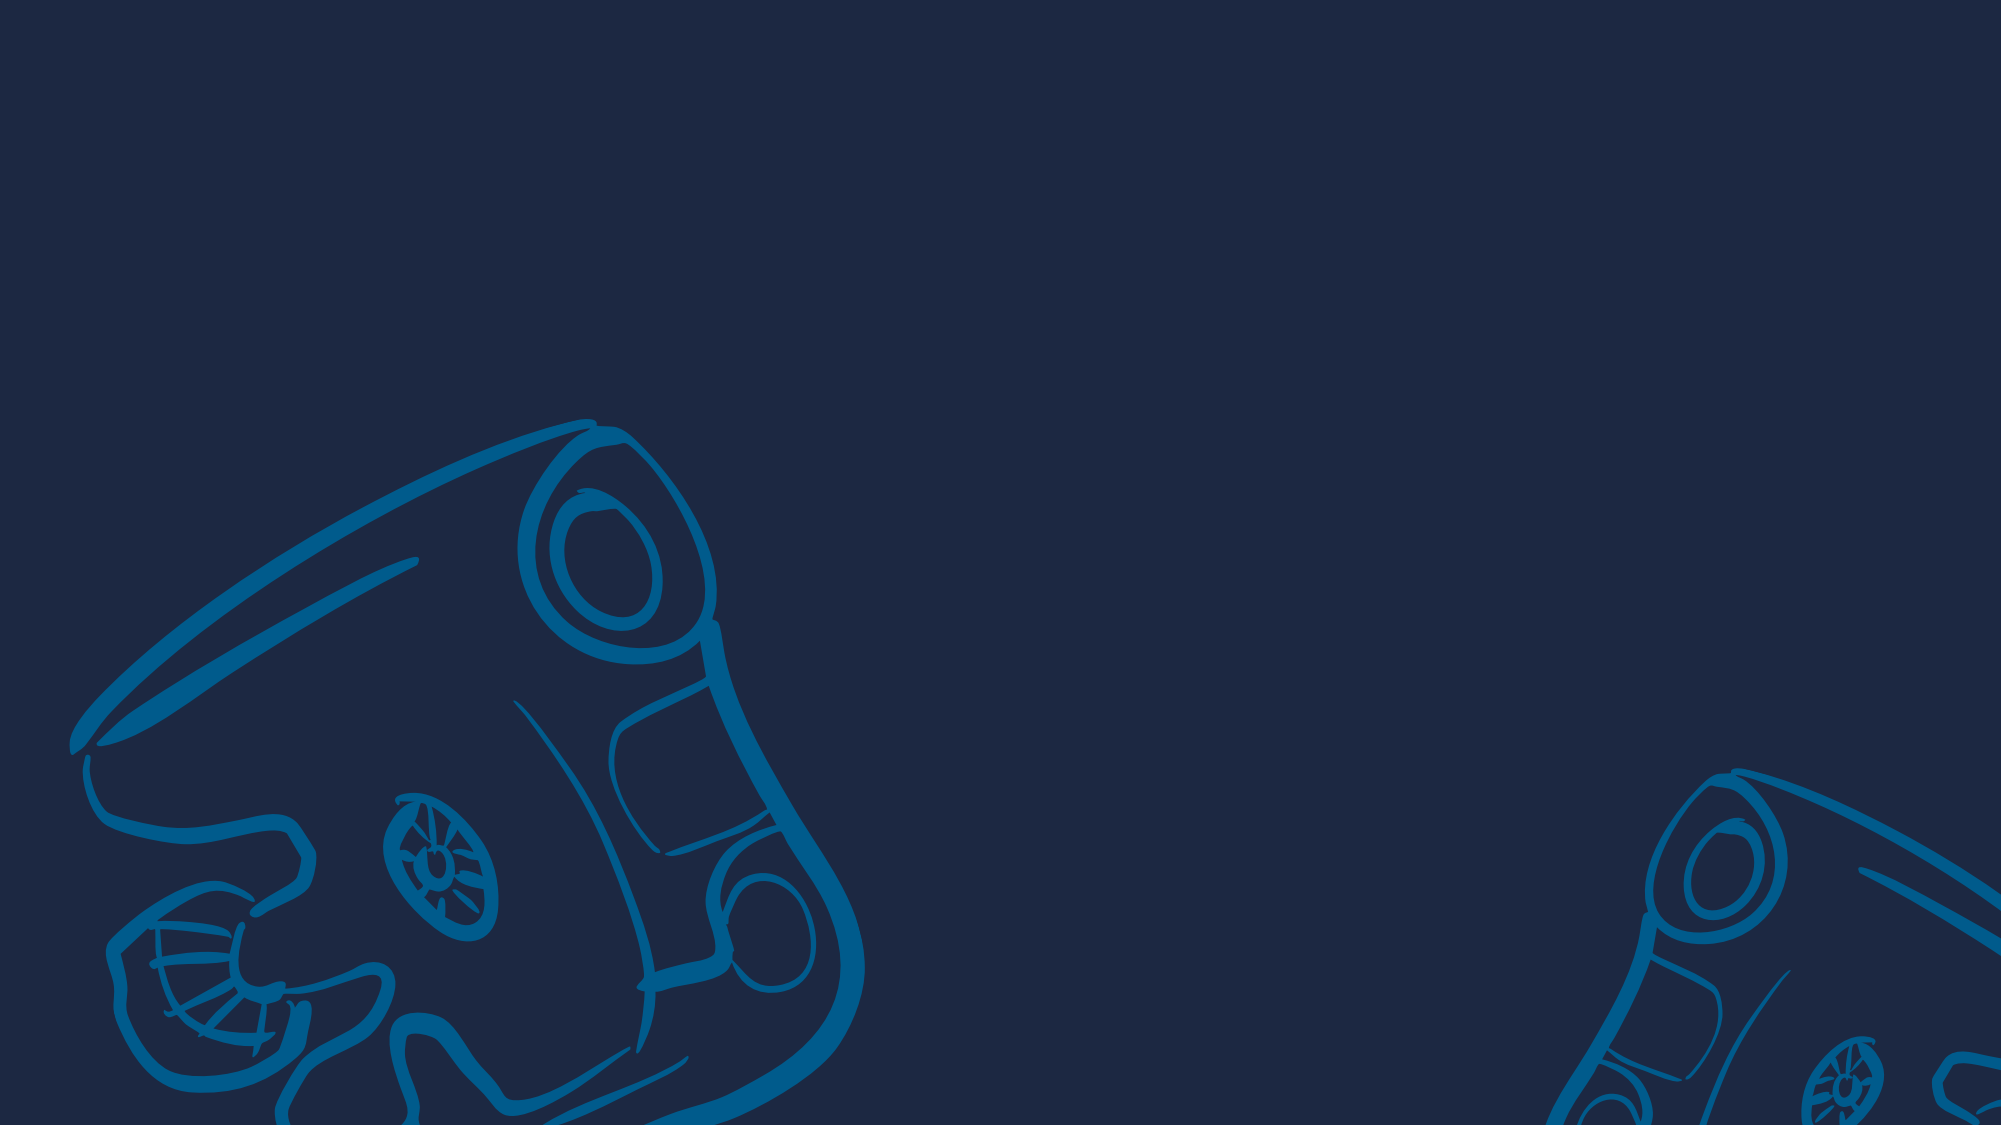
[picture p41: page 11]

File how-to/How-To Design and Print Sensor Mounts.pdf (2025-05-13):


How-To Design and Print
Sensor Mounts

# How-To Design Sensor Mounts

# Distances


The space between a hole and a
corner is less than 1 cm due to the
thickness of the walls, be mindful of
this if designing for parts that might
need to be near a corner

The space between two holes are 2 cm, when
designing parts, its good to have the space
from the hole to the edge be 1 cm to allow for
other fasteners beside it.

# Fillet

# How-To Design Sensor Mounts


The connecting pieces have a fillet of
2.5 mm, when designing parts around
it, use a fillet of the same size on inner
corners.

# Example fastener

# How-To Design Sensor Mounts


This is a simple and good
attachment method for
lighter sensors that does not
require much material and
offers many placement
options.

## Screws and nuts

# How-To Design Sensor Mounts


M4 screws and nuts are good for fastening the sensor mounts
screws: https://no.rs-online.com/web/p/socket-screws/1247349
nuts: https://no.rs-online.com/web/p/hex-nuts/0189579?gb=s

To make the parts airtight

increase | to | . It is
also recommended to set
to for increased
durability.
infill density | 100%
| | wall
loops/thickness | 5

Airtight and
100% infill

# How-To Print Sensor Mounts

# Printer settings to be mindful of

v Import file into your preferred slicer program.

v Settings to be mindful of}

lr Filament. Recommended to use
. These work well in saltwaterv
r 100% infill vs. open model and gyroid infill

To prevent implosion in deeper waters, the parts

should either be | or | to let water
run through. Which setting you should use when depends on the desired durability, and which one we recommend for which part is specified in the guides on the next slides.

PETG or PETG-CF

100% infill open

Note:
The examples are from the bamboo slicer but

equivalent settings will exist on every slicer program.

You only need to change the specified settings, the

rest is fine as-is.

To make an open solution, set
and/or | to | and
change | pattern to

## top bottom shell layer 0 sparse infill “Gyroid”

Open model and
gyroid infill

# How-To Print Sensor Mounts

# Several in one bed


Time: ca. 4h and 7 minutes

Edited printer settings

Recommended to use the Open
model settings

Bottom shell layers: 0
Infill pattern: gyroid
support enabled
support type: tree/organic

(the rest is fine as is)


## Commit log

2025-05-15 Rename dvlfete.png to DVL mount.png
2025-05-15 Rename Untitled-2.png to Whole frame.png
2025-05-15 Rename Untitled-36.png to Connecting frame.png
2025-05-15 Rename onarfete.png to Sonar mount.png
2025-05-15 Rename ublfeteticc.png to USBL mount.png
